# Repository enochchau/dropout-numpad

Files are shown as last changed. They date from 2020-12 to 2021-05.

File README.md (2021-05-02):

# Dropout 

(mechanical numpad w/ roatry encoder)

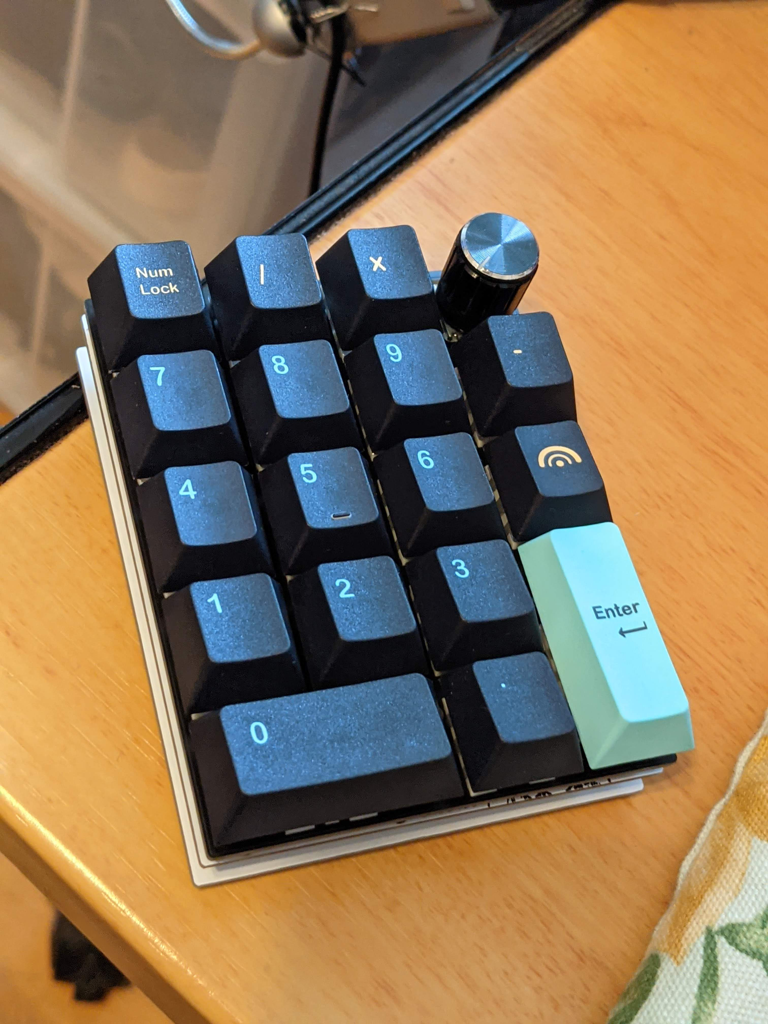
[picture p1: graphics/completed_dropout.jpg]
droput-completed


## Firmware
Dropout uses [QMK](https://github.com/qmk/qmk_firmware).
For now you'll have to use my fork of QMK under [the dropout-numpad branch](https://github.com/ec965/qmk_firmware/tree/dropout-numpad/keyboards/dropout).
If you know what you're doing, you can also copy the firmware files from this repository into your local QMK repository and compile it that way.

## Parts

### Case Parts
Amount | Part | Dimensions
--- | --- | ---
5 | M2 F-F standoffs | minimum: 13mm (mini usb) or 11mm (micro-usb)
10 | M2 screws | 5mm
4 | rubber bumpon feet

Sandwhich! case (parts in this order from top down)

1. Plate
2. PCB
3. Base

### PCB Components
Amount | Part | Package
--- | --- | ---
18 | diodes (1n4148 recommended) | SOD-123 (SMD) or DO-35 (THT)
1 | resistor (333 Ohms) | 0805
2 | capacitors (10nF) | 0805
1 | led | 1.8mm
1 | rotary encoder | EC-11
1 | push button | SPST PTS810
1 | pro-micro | usb-mini or usb-micro
16 | mx-switches | 
2 | 2U stabilizers | 

#### Notes
* Encoder can be swapped for a 1u switch.
  - If opting for the 1u switch, capacitors are not needed.
* If using encoder, capacitors can be omitted but resulting encoder signal will not be as smooth.
* Resistor can be omitted if num-lock led is not used.

## Build Guide

* The bottom of the PCB is the side without the stencil art of the person.
* The top of the PCB is the side with the stencil art person on it.
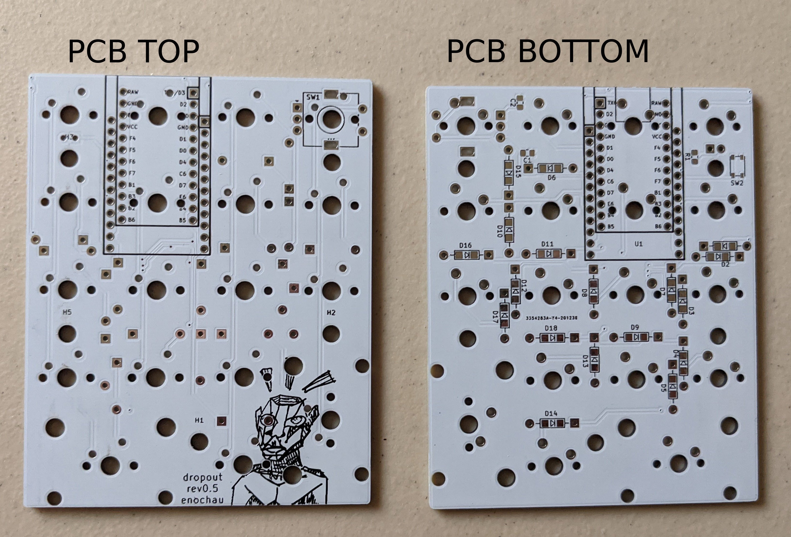
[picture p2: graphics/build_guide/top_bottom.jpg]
top and bottom of pcb


1. Start on the bottom of the PCB. Solder on all the diodes. Make sure that the diodes are in the correct direction. The diagram below should match up to the the symbol on the schematic and the physical diodes.
diode diagram
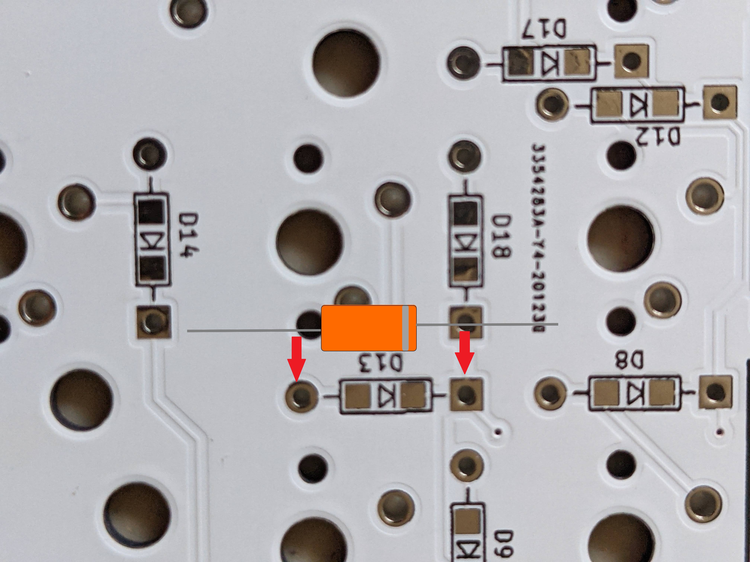
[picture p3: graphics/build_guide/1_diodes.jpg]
PCB diodes


2. Solder on capacitors C1 and C2. These are located near the rotary encoder.
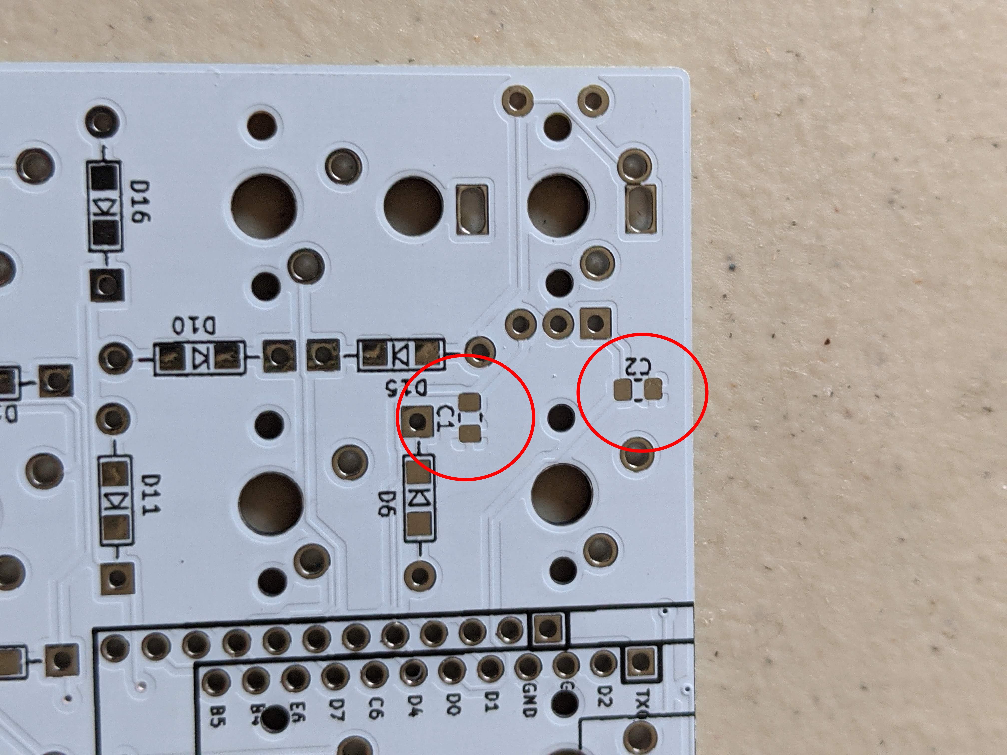
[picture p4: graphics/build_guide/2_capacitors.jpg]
capacitor location

capacitor soldered on

3. Solder on the resistor R1. It is near the num lock key. This resistor is to limit the current going to the num-lock led.

4. Solder on the SPST reset switch.
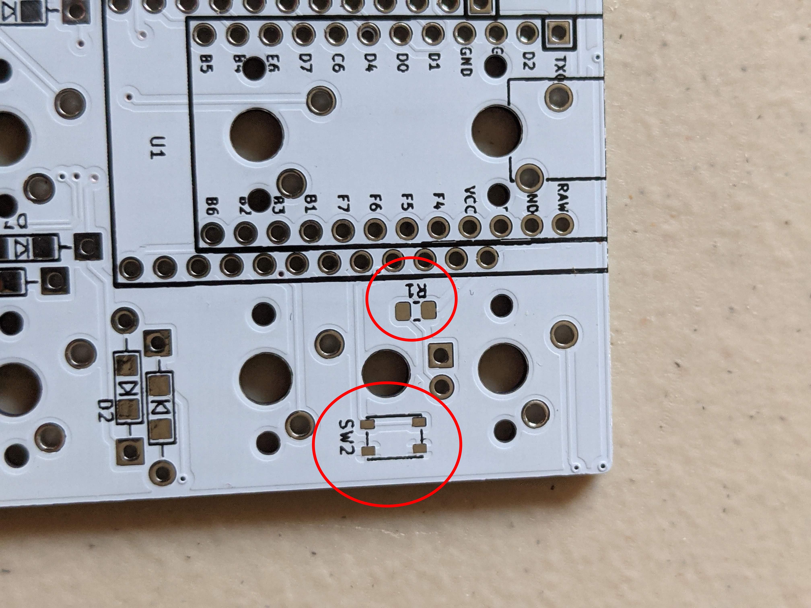
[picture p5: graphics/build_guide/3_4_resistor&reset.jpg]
resistor and reset switch

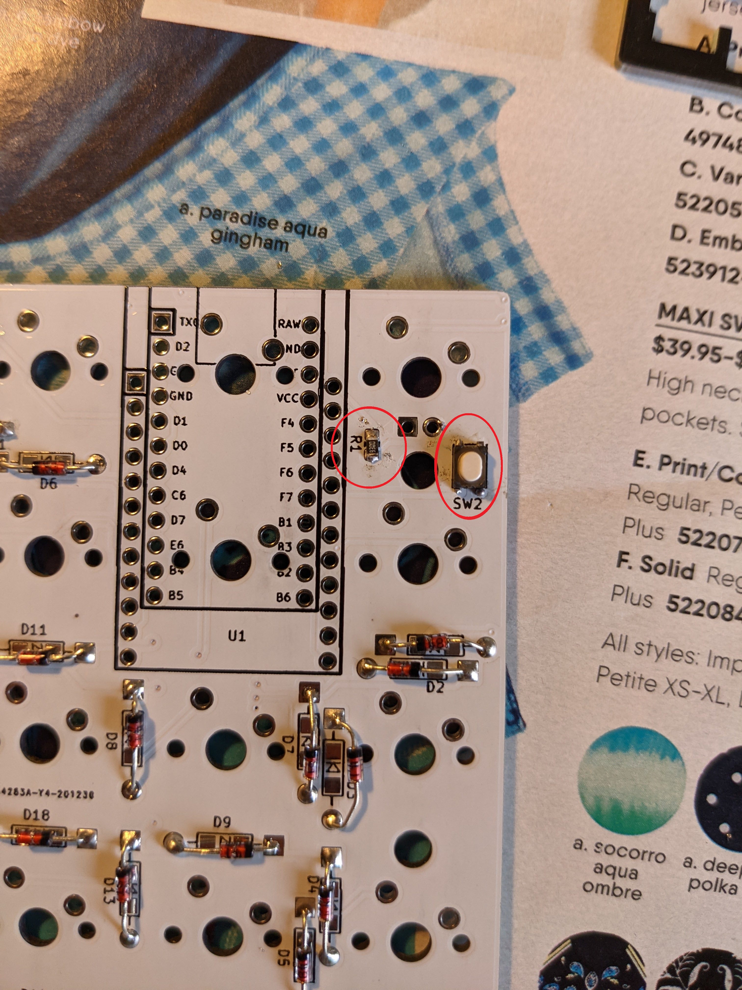
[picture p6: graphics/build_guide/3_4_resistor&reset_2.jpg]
resistor and reset switch soldered on


5. Solder on the Pro Micro header pins with the short side down. DO NOT solder on the Pro Micro.
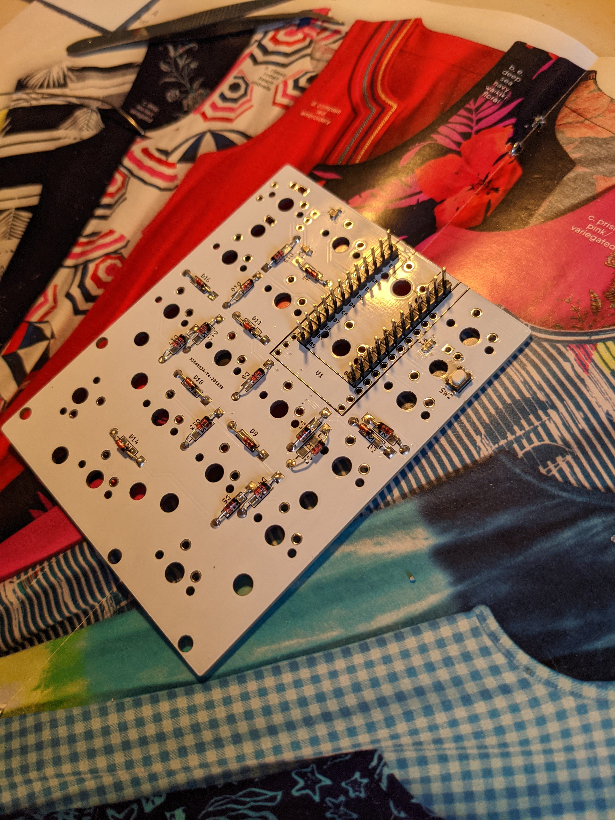
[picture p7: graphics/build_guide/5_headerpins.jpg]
head pin direction


6. Solder on the rotary encoder.
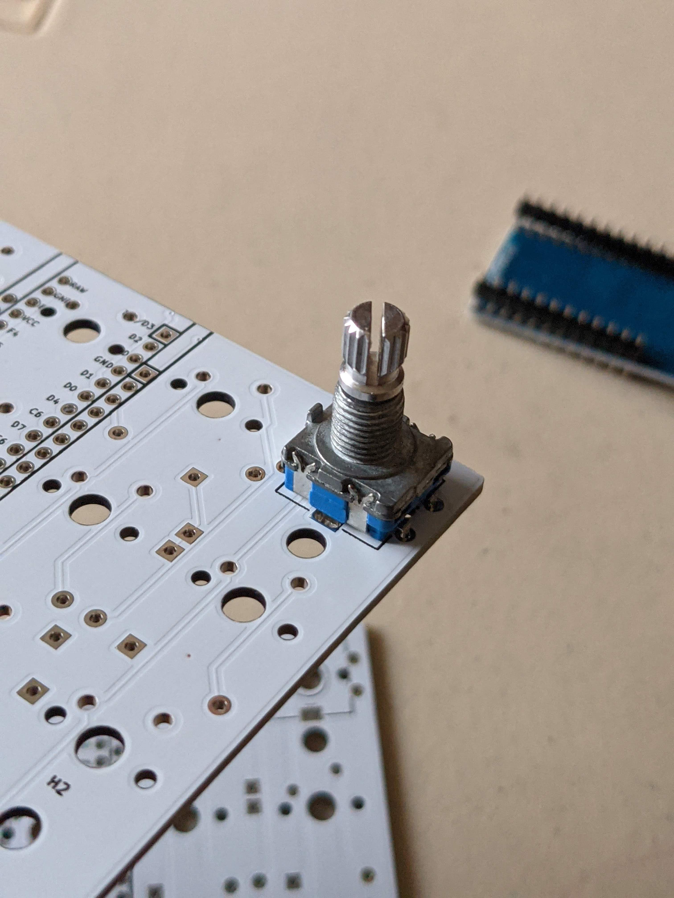
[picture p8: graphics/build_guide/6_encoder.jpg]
encoder


7. Flip the board over to the top side. You should now see the stencil art of the the person. Put two 2U stablizers on the board for the Zero and Enter keys.
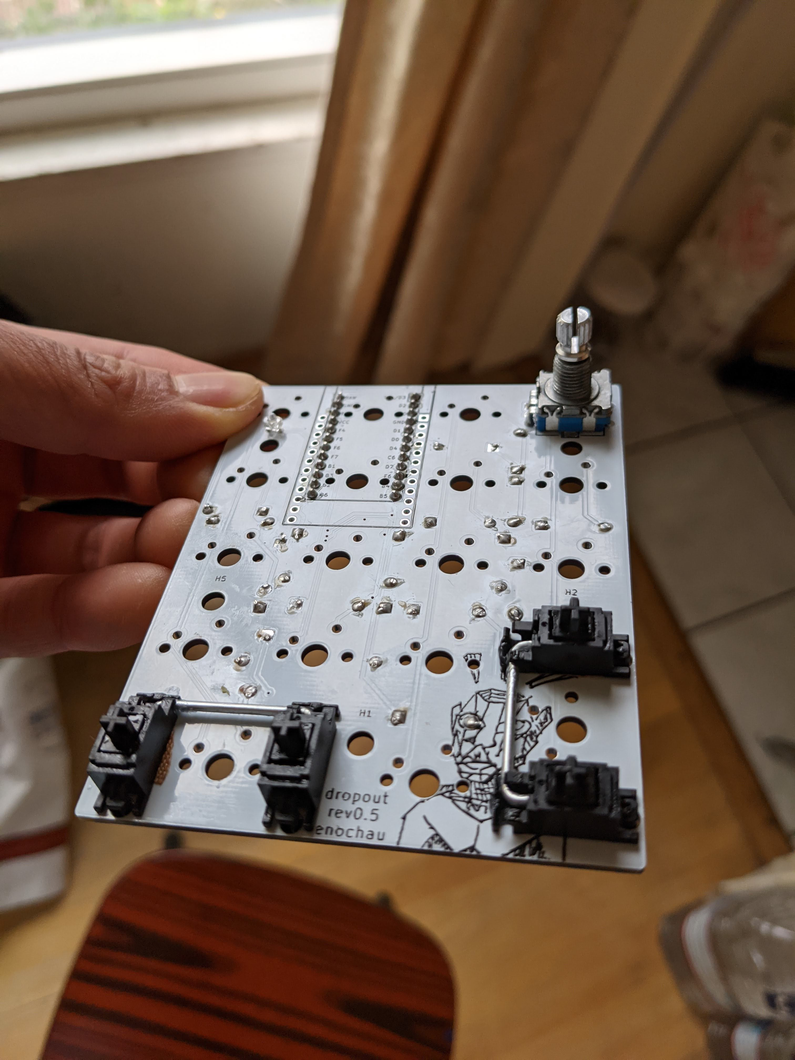
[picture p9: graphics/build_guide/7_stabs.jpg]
stabs on pcb

    1. If you are using Kailh Box switches, solder on the num-lock LED before putting the switch on the board.
    2. If you are using regular Cherry, Gateron, etc. you can wait to solder the num-lock LED after all the switches are soldered on.

The polarity of the led is shown below.
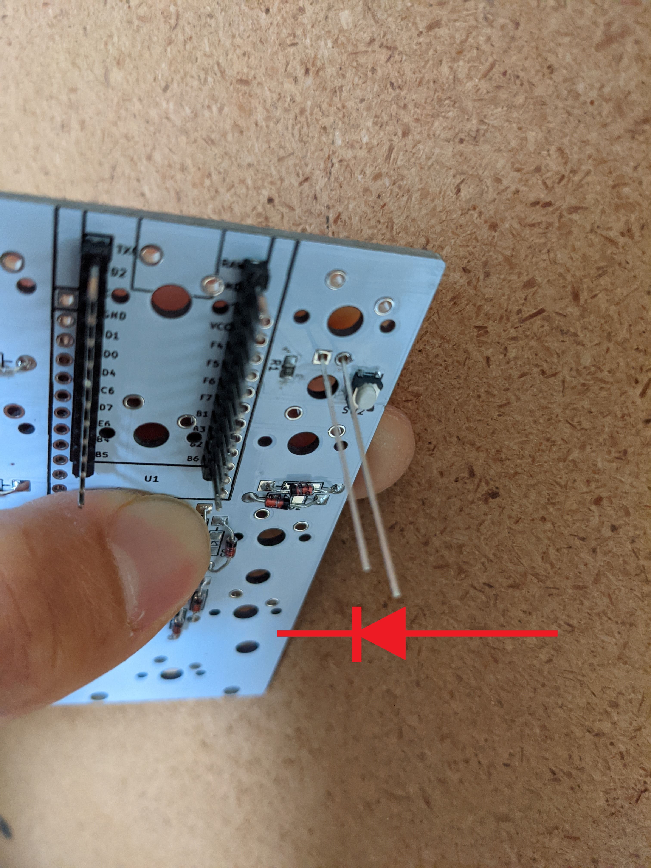
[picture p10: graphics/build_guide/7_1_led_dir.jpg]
led direction


8. Put the switches on the plate. Line up the plate with the pcb and push the two parts together. There may be some friction but as long as none of the switch pins get bent it is okay.
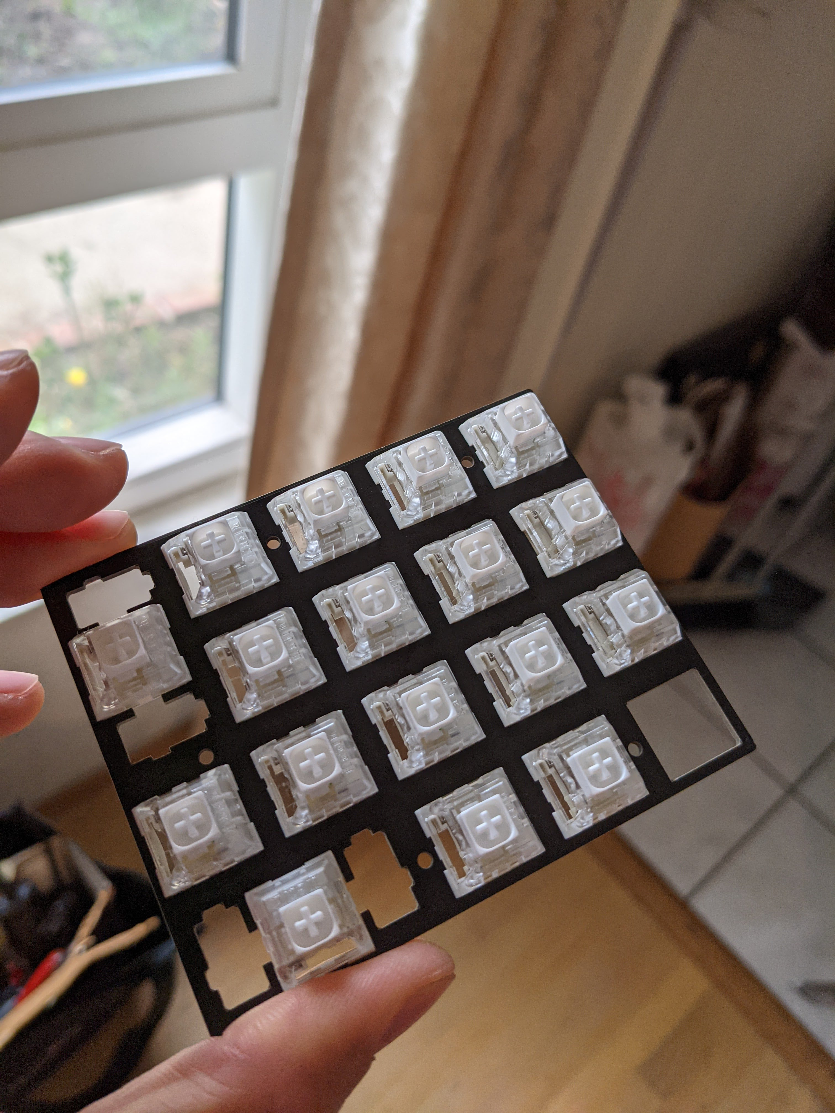
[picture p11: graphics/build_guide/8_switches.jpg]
switches in plate


9. Flip the PCB over to the bottom side. As you solder on the switches, apply some pressure to push the plate into the PCB to ensure that the switches are flush with the PCB.

10. Tape the Pro Micro onto the header pins. 
Clip the long header pins to be flush with the holes on the Pro Micro.
Then, solder the Pro Micro to the header pins.
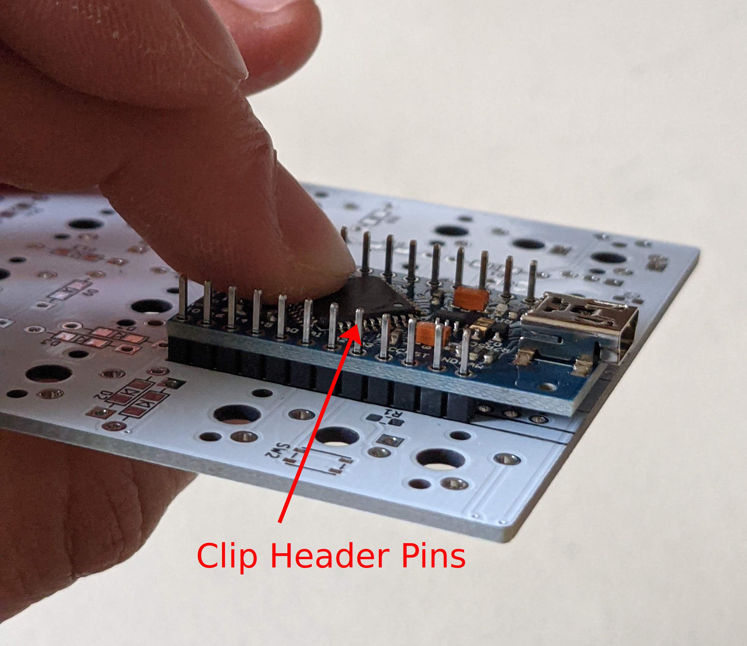
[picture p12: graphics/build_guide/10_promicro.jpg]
pro micro clip pins

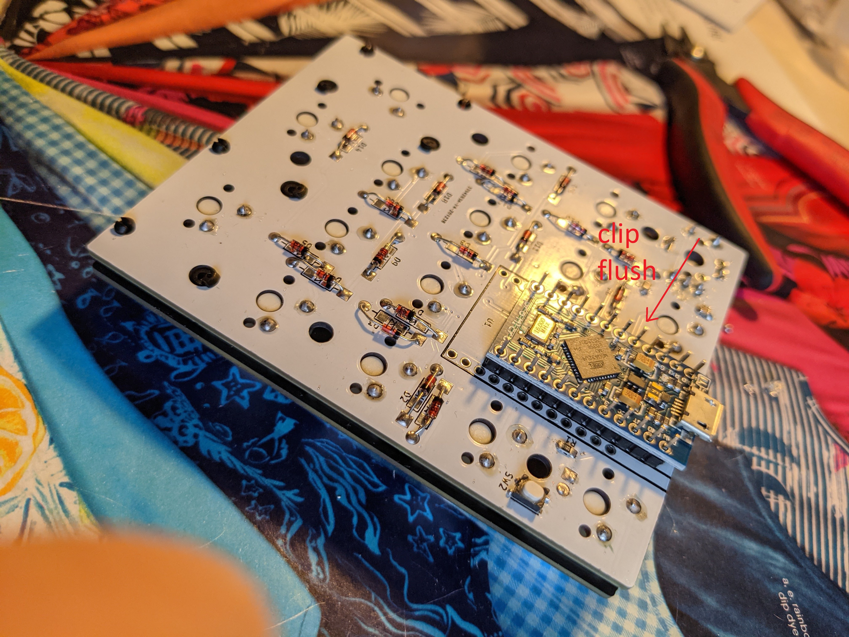
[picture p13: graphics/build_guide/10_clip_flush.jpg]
clip flush


11. Put the standoffs through the holes on the top of the plate and screw them in.

12. Get the bottom plate and screw the other end of the standoffs into the bottom plate. The standoffs should go through the holes in the PCB.
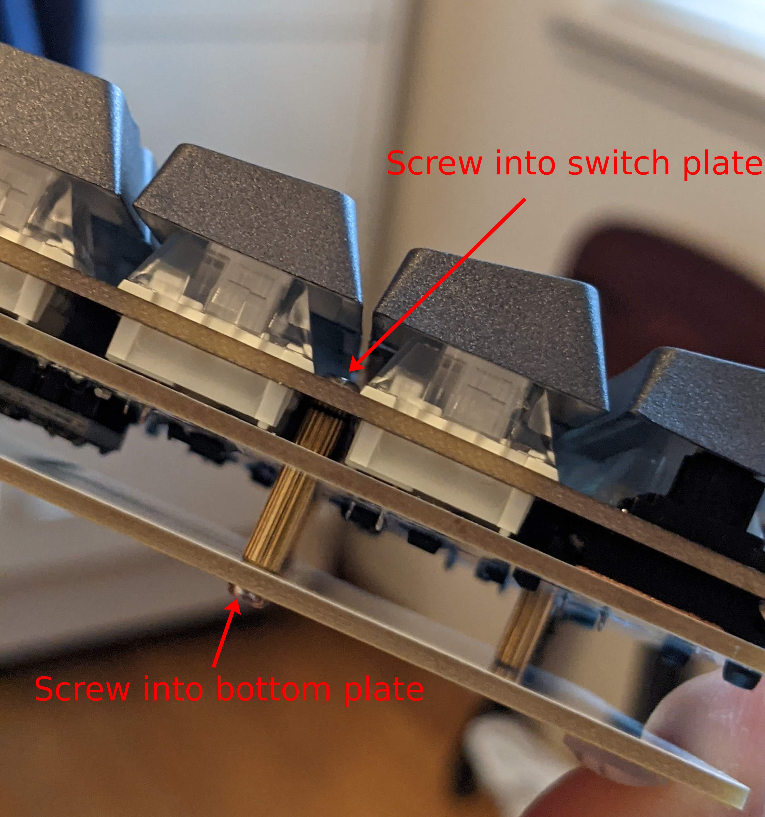
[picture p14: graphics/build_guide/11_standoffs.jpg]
stand-offs


13. Place rubber feet onto the bottom of the numpad.
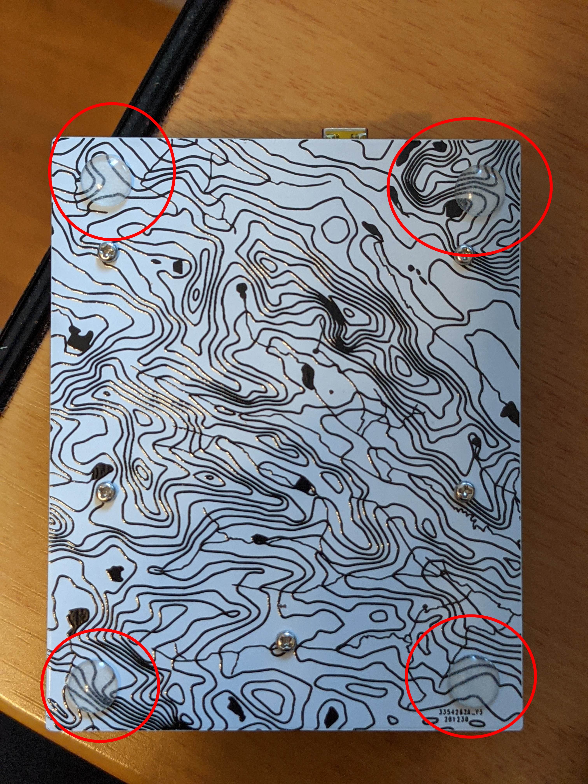
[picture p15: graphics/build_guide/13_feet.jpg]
rubber feet placement


## PCBs

* rev 0.5
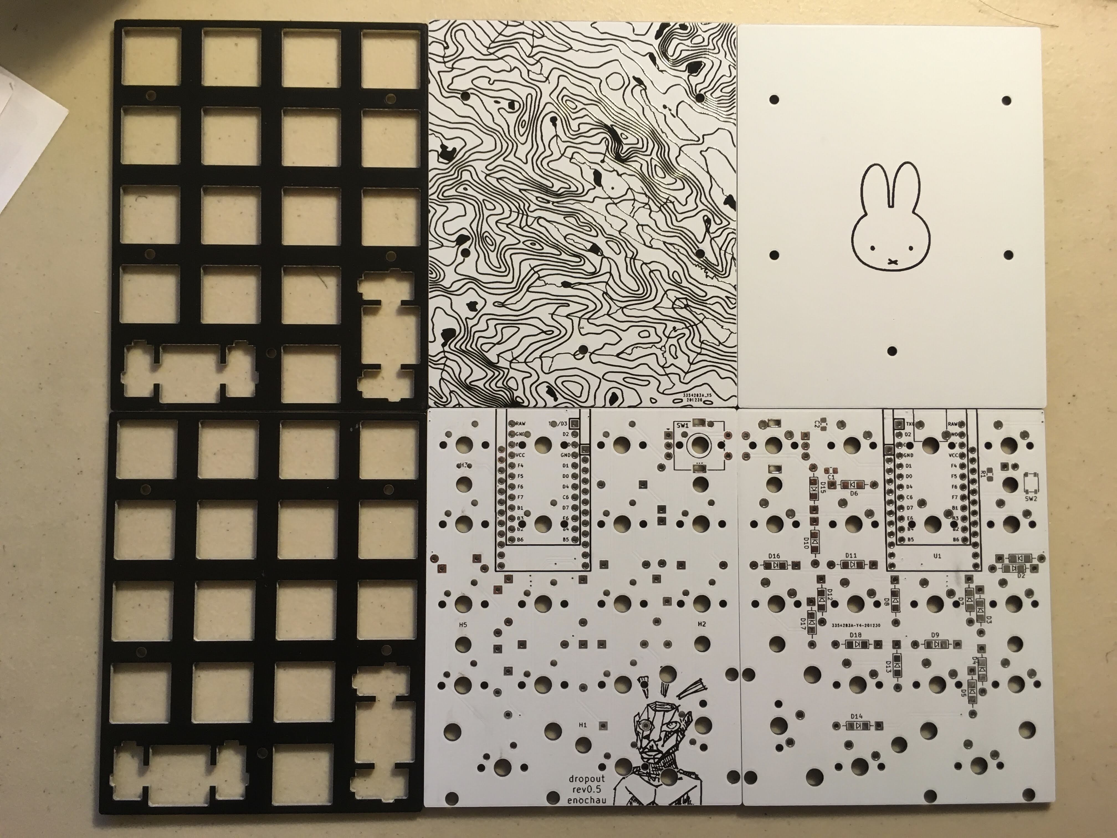
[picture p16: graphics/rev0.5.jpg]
rev0.5

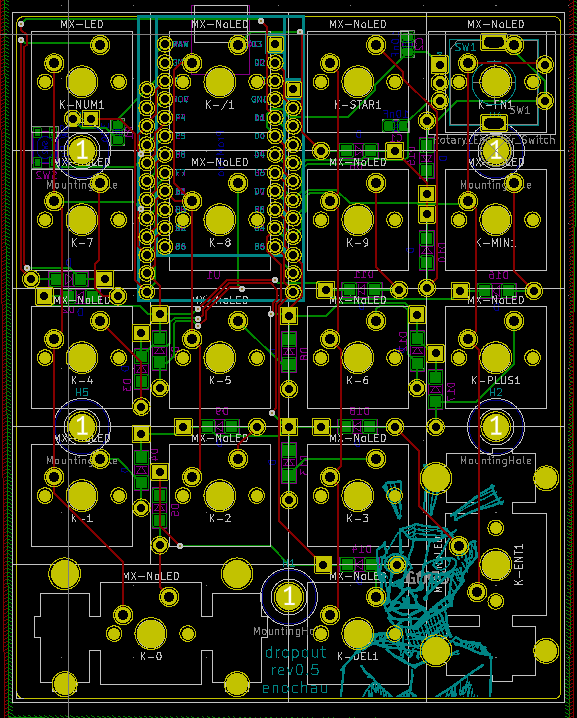
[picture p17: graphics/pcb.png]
pcb PCB

* rev 0.1
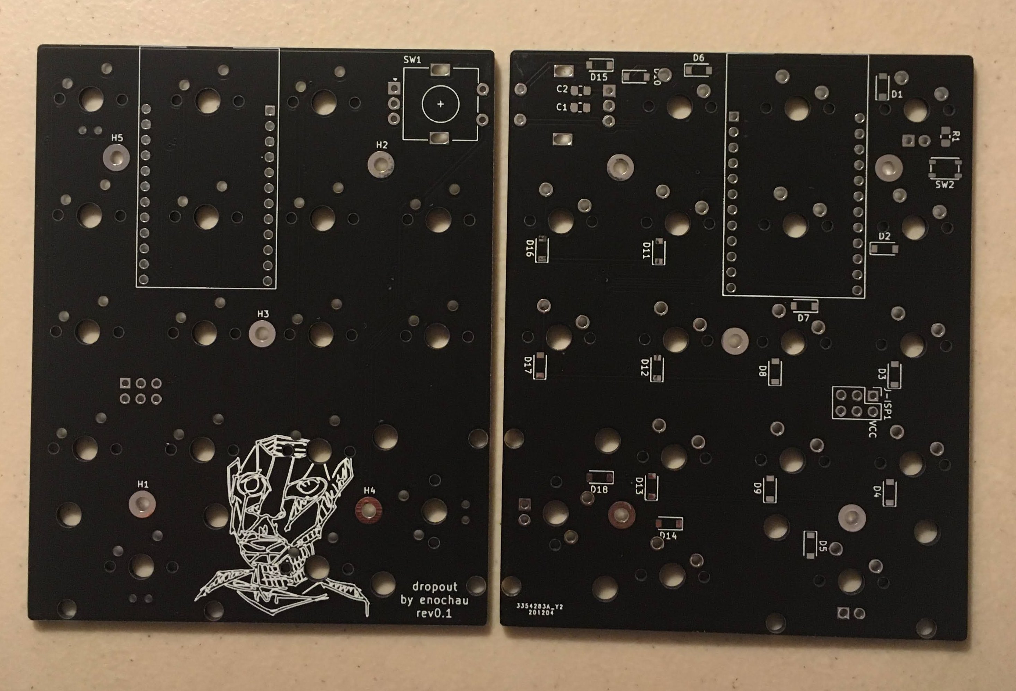
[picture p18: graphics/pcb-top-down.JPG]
rev0.1


## License

Hardware designs are under the MIT license. QMK is under the GPL v2 license therefore, the firmware is also under the GPLv2 license.

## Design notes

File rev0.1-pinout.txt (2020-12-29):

Rows
0: D1
1: B2
2: E6
3: B4
4: B5

Cols
0: B3
1: B1
2: D7
3: C6

Backlight: B6

Encoder:
A: D0
B: D4

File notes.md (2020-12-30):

# Notes

## Updates
PCBs are labelled with revision number in the lower right corner.

* 12/29 - Rev0.5 Fixed plate outline to match stab orientation. Got rid of panelization.
* 12/29 - Rev0.5 Flipped ProMicro and redrew traces. There isn't enough clearance for the pro-micro to sit flush against the pcb. Rev0.5 now uses the same pinout as Rev0.1.
* 12/28 - Rev0.5 Replaced SOD123 diode footprints with THT/SOD123 dual footprint. Removed ISP and I2C header pins. Cleaned up schematic and footprints.
* 12/11 - Rev0.4 Added compatibility for ProMicro with mini-usb or micro-usb on same pcb, flipped orientation of ProMicro, and cleaned up traces.
Added option for switch or rotary encoder. Added I2C header.
* 12/6 - Rev0.3 Added mouse-bites to print all parts on a single PCB.
* 12/? - Rev0.2 uses ProMicro (mini-usb). Mounting holes have been moved to prevent interference with stablizier wire. Board outline was also slightly adjusted. I also created a plate pcb. Because some dimensions changed between rev0.1 and rev0.2, the plate will not fit on older revisions.
* 12/? - Rev0.1 uses ProMicro with mini-usb as can be found by various retailers elsewhere on the internet. 
Dimensions for the ProMicro mini-usb are 39.5mm x 23mm. I do not garantee that your ProMicro will fit the board.
* 12/? - Rev0 uses ProMicro with micro-usb as designed by [Sparkfun](https://www.sparkfun.com/products/12640).

### M2 F-F standoff calculations:
#### For mini-usb
**5mm** _from top of plate to top of pcb_ **- 1.6mm** _thickness of plate_ **+ 1.6mm** _thickness of pcb_ **+ ~6mm** _thickness pro-micro usb mini_ **+ 2mm** _thickness of header pins_ **= 13mm**
#### For micro-usb
**5mm** _from top of plate to top of pcb_ **- 1.6mm** _thickness of plate_ **+ 1.6mm** _thickness of pcb_ **+ ~4mm** _thickness pro-micro usb mini_ **+ 2mm** _thickness of header pins_ **= 11mm**

## Q&A
Where does the name come from?

I designed this shortly after deciding to dropout.

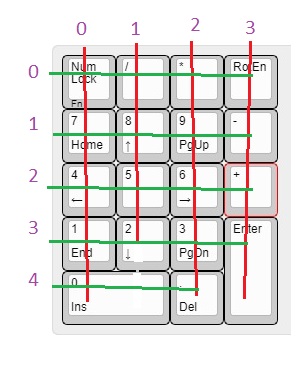
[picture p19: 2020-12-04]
graphics/design_files/keyboard-layout.jpg

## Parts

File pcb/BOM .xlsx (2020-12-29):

Reference | Quantity | Value | Footprint | Datasheet | Notes
D1 D2 D3 D4 D5 D6 D7 D8 D9 D10 D11 D12 D13 D14 D15 D16 D17 D18 | 18 | D | Diode_SMD:D_SOD-123 | ~
H1 H2 H3 H4 H5 | 5 | MountingHole | MountingHole:MountingHole_2.2mm_M2_Pad | ~ | screws and poles (8mm)
K-/1 K-STAR1 K-MIN1 K-PLUS1 K-1 K-DEL1 K-2 K-3 K-4 K-5 K-6 K-7 K-8 K-9 | 14 | MX-NoLED | MX_Only:MXOnly-1U-NoLED | Kailh Box Whites
K-0 K-ENT1 | 2 | MX-NoLED | MX_Only:MXOnly-2U-NoLED |  | 2u stabs
K-NUM1 | 1 | MX-LED | MX_Only:MXOnly-1U
R1 | 1 | 333 | Resistor_SMD:R_0805_2012Metric_Pad1.15x1.40mm_HandSolder | ~
SW1 | 1 | Rotary_Encoder_Switch | Rotary_Encoder:RotaryEncoder_Alps_EC11E-Switch_Vertical_H20mm | ~ | knob and encoder
SW2 | 1 | SW_Push | Button_Switch_SMD:SW_SPST_PTS810 | ~
U1 | 1 | ProMicro | promicro:ProMicro |  | mini usb, 39.5mmx23mm
PCB
C1 C2 | 2 | 10nF | 805

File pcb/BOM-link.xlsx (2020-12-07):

Reference | Quantity | Value | Footprint | Datasheet | amount | price | Total | Notes | Purchase link
D1 D2 D3 D4 D5 D6 D7 D8 D9 D10 D11 D12 D13 D14 D15 D16 D17 D18 | 18 | D | Diode_SMD:D_SOD-123 | ~ | 40 | 1.44 | 5.76 |  | https://www.digikey.com/en/products/detail/diodes-incorporated/1N4148W-7-F/814371
H1 H2 H3 H4 H5 | 5 | MountingHole | MountingHole:MountingHole_2.2mm_M2_Pad | ~ |  |  | 3.1 | screws and poles (8mm)
K-/1 K-STAR1 K-MIN1 K-PLUS1 K-1 K-DEL1 K-2 K-3 K-4 K-5 K-6 K-7 K-8 K-9 | 14 | MX-NoLED | MX_Only:MXOnly-1U-NoLED | Kailh Box Whites | 70 |  | 27.3 | box whites | https://www.aliexpress.com/item/32879369291.html
K-0 K-ENT1 | 2 | MX-NoLED | MX_Only:MXOnly-2U-NoLED |  | 4 |  | 5.9 | 2u stabs | https://www.aliexpress.com/item/32831318362.html?scm_id=1007.13338.183347.0&scm-url=1007.13338.183347.0
K-NUM1 | 1 | MX-LED | MX_Only:MXOnly-1U
R1 | 1 | 330 | Resistor_SMD:R_0805_2012Metric_Pad1.15x1.40mm_HandSolder | ~ | 5 |  | 0.5 |  | https://www.digikey.com/en/products/detail/te-connectivity-passive-product/CRG0805F330R/2380889
SW1 | 1 | Rotary_Encoder_Switch | Rotary_Encoder:RotaryEncoder_Alps_EC11E-Switch_Vertical_H20mm | ~ |  |  | 3.75 | knob and encoder | https://www.aliexpress.com/item/32873198060.html?scm_id=1007.13339.169870.0&scm-url=1007.13339.169870.0 | https://www.aliexpress.com/item/32889562286.html?spm=2114.12010615.8148356.17.2f6b50311E8rPt
SW2 | 1 | SW_Push | Button_Switch_SMD:SW_SPST_PTS810 | ~ | 5 |  | 1.6 |  | https://www.digikey.com/en/products/detail/c-k/PTS810-SJM-250-SMTR-LFS/4176610
U1 | 1 | ProMicro | promicro:ProMicro |  |  |  |  | mini usb, 39.5mmx23mm
PCB |  |  |  |  |  |  | 9.12 |  | jlcjpcb.com
C1 C2 | 2 | 10nF | 805 |  | 10 | 0.14 | 0.7 |  | https://www.digikey.com/en/products/detail/kemet/C0805X103K1RAC3316/10315780
 |  |  |  |  |  | Total | 57.03

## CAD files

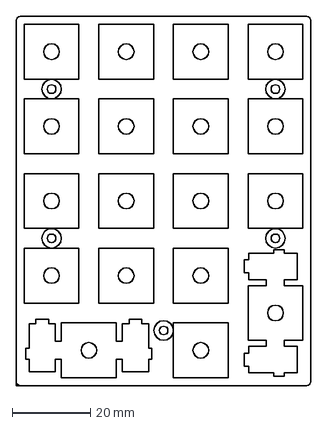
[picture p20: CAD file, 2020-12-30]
graphics/design_files/outline.dxf
75.1 x 94.2 mm

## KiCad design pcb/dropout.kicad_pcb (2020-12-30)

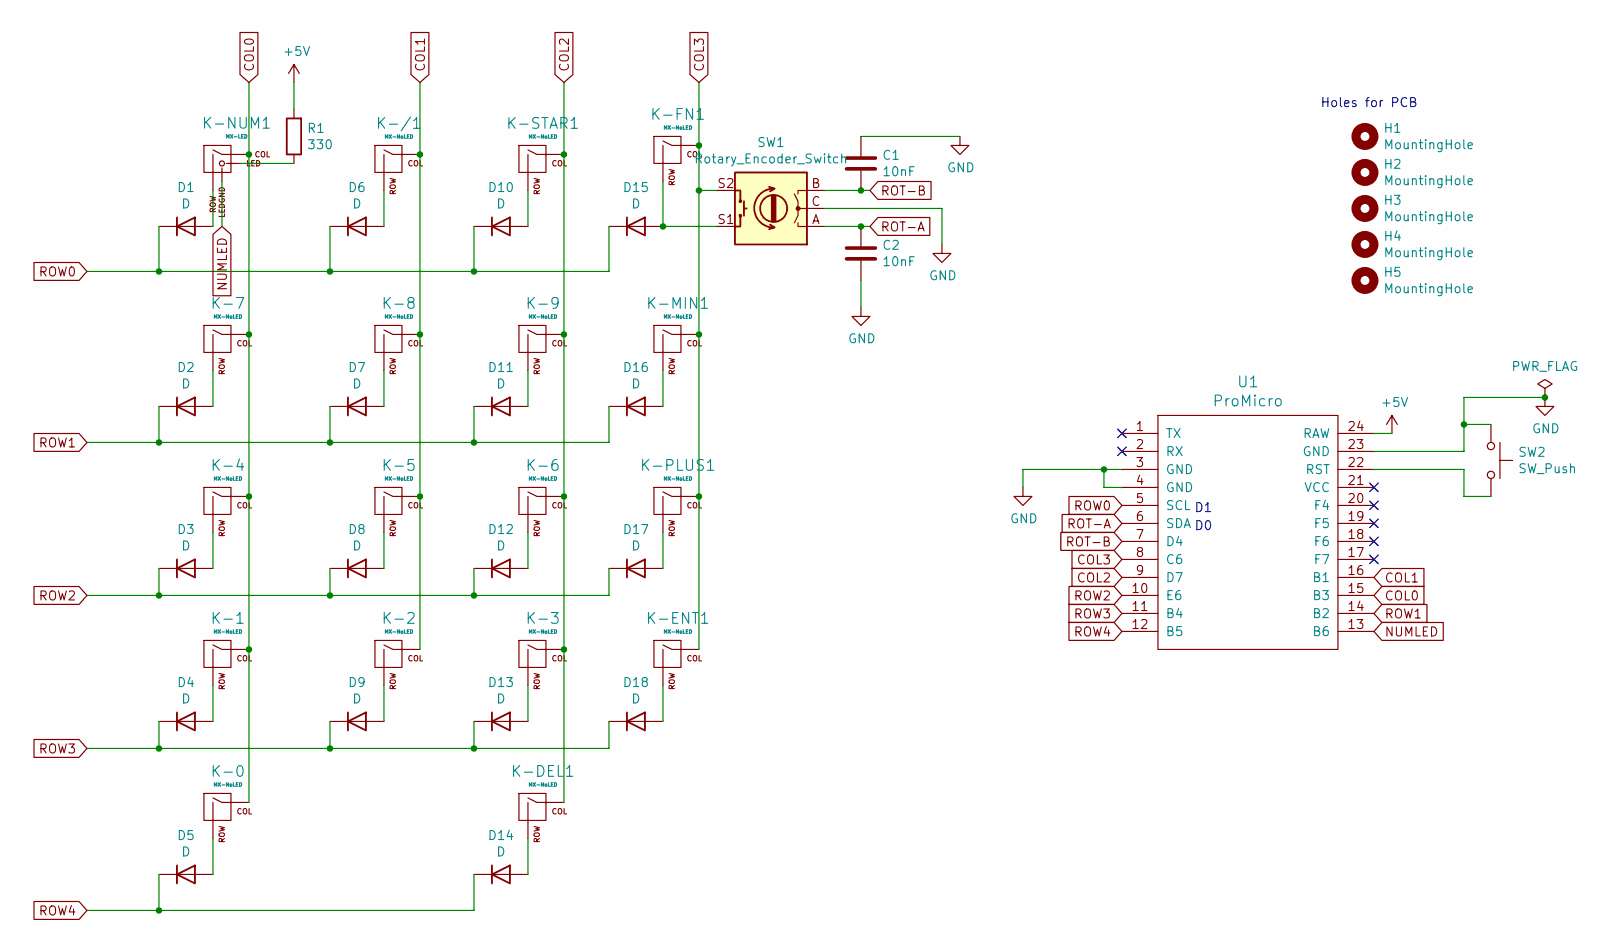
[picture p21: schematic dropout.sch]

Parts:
C1, C2: 10nF; C_0805_2012Metric_Pad1.15x1.40mm_HandSolder
D1, D2, D3, D4, D5, D6, D7, D8, D9, D10, D11, D12, D13, D14, D15, D16, D17, D18: D; Diode_TH_SOD123
H1, H2, H3, H4, H5: MountingHole; MountingHole_3.7mm
K-0: MX-NoLED; MXOnly-2U-ReversedStabilizers-NoLED
K-1, K-2, K-3, K-4, K-5, K-6, K-7, K-8, K-9: MX-NoLED; MXOnly-1U-NoLED
K-/1: MX-NoLED; MXOnly-1U-NoLED
K-DEL1: MX-NoLED; MXOnly-1U-NoLED
K-ENT1: MX-NoLED; MXOnly-2U-ReversedStabilizers-NoLED
K-FN1: MX-NoLED; MXOnly-1U-NoLED
K-MIN1: MX-NoLED; MXOnly-1U-NoLED
K-NUM1: MX-LED; MXOnly-1U
K-PLUS1: MX-NoLED; MXOnly-1U-NoLED
K-STAR1: MX-NoLED; MXOnly-1U-NoLED
R1: 330; R_0805_2012Metric_Pad1.15x1.40mm_HandSolder
SW1: Rotary_Encoder_Switch; RotaryEncoder_Alps_EC11E-Switch_Vertical_H20mm
SW2: SW_Push; SW_SPST_PTS810
U1: ProMicro; ProMico_mini&micro

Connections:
+5V: R1.2, U1.24 (RAW)
COL0: K-0.1 (COL), K-1.1 (COL), K-4.1 (COL), K-7.1 (COL), K-NUM1.1 (COL), U1.15 (B3)
COL1: K-2.1 (COL), K-5.1 (COL), K-8.1 (COL), K-/1.1 (COL), U1.16 (B1)
COL2: K-3.1 (COL), K-6.1 (COL), K-9.1 (COL), K-DEL1.1 (COL), K-STAR1.1 (COL), U1.9 (D7)
COL3: K-ENT1.1 (COL), K-FN1.1 (COL), K-MIN1.1 (COL), K-PLUS1.1 (COL), SW1.S2, U1.8 (C6)
GND: C1.1, C2.2, SW1.C, SW2.1, U1.3 (GND), U1.4 (GND), U1.23 (GND)
NUMLED: K-NUM1.4 (LEDGND), U1.13 (B6)
unnamed: D1.2 (A), K-NUM1.2 (ROW)
unnamed: D2.2 (A), K-7.2 (ROW)
unnamed: D3.2 (A), K-4.2 (ROW)
unnamed: D4.2 (A), K-1.2 (ROW)
unnamed: D5.2 (A), K-0.2 (ROW)
unnamed: D6.2 (A), K-/1.2 (ROW)
unnamed: D7.2 (A), K-8.2 (ROW)
unnamed: D8.2 (A), K-5.2 (ROW)
unnamed: D9.2 (A), K-2.2 (ROW)
unnamed: D10.2 (A), K-STAR1.2 (ROW)
unnamed: D11.2 (A), K-9.2 (ROW)
unnamed: D12.2 (A), K-6.2 (ROW)
unnamed: D13.2 (A), K-3.2 (ROW)
unnamed: D14.2 (A), K-DEL1.2 (ROW)
unnamed: D15.2 (A), K-FN1.2 (ROW), SW1.S1
unnamed: D16.2 (A), K-MIN1.2 (ROW)
unnamed: D17.2 (A), K-PLUS1.2 (ROW)
unnamed: D18.2 (A), K-ENT1.2 (ROW)
unnamed: K-NUM1.3 (LED), R1.1
unnamed: SW2.2, U1.22 (RST)
ROT-A: C2.1, SW1.A, U1.6 (SDA)
ROT-B: C1.2, SW1.B, U1.7 (D4)
ROW0: D1.1 (K), D6.1 (K), D10.1 (K), D15.1 (K), U1.5 (SCL)
ROW1: D2.1 (K), D7.1 (K), D11.1 (K), D16.1 (K), U1.14 (B2)
ROW2: D3.1 (K), D8.1 (K), D12.1 (K), D17.1 (K), U1.10 (E6)
ROW3: D4.1 (K), D9.1 (K), D13.1 (K), D18.1 (K), U1.11 (B4)
ROW4: D5.1 (K), D14.1 (K), U1.12 (B5)

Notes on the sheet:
Holes for PCB

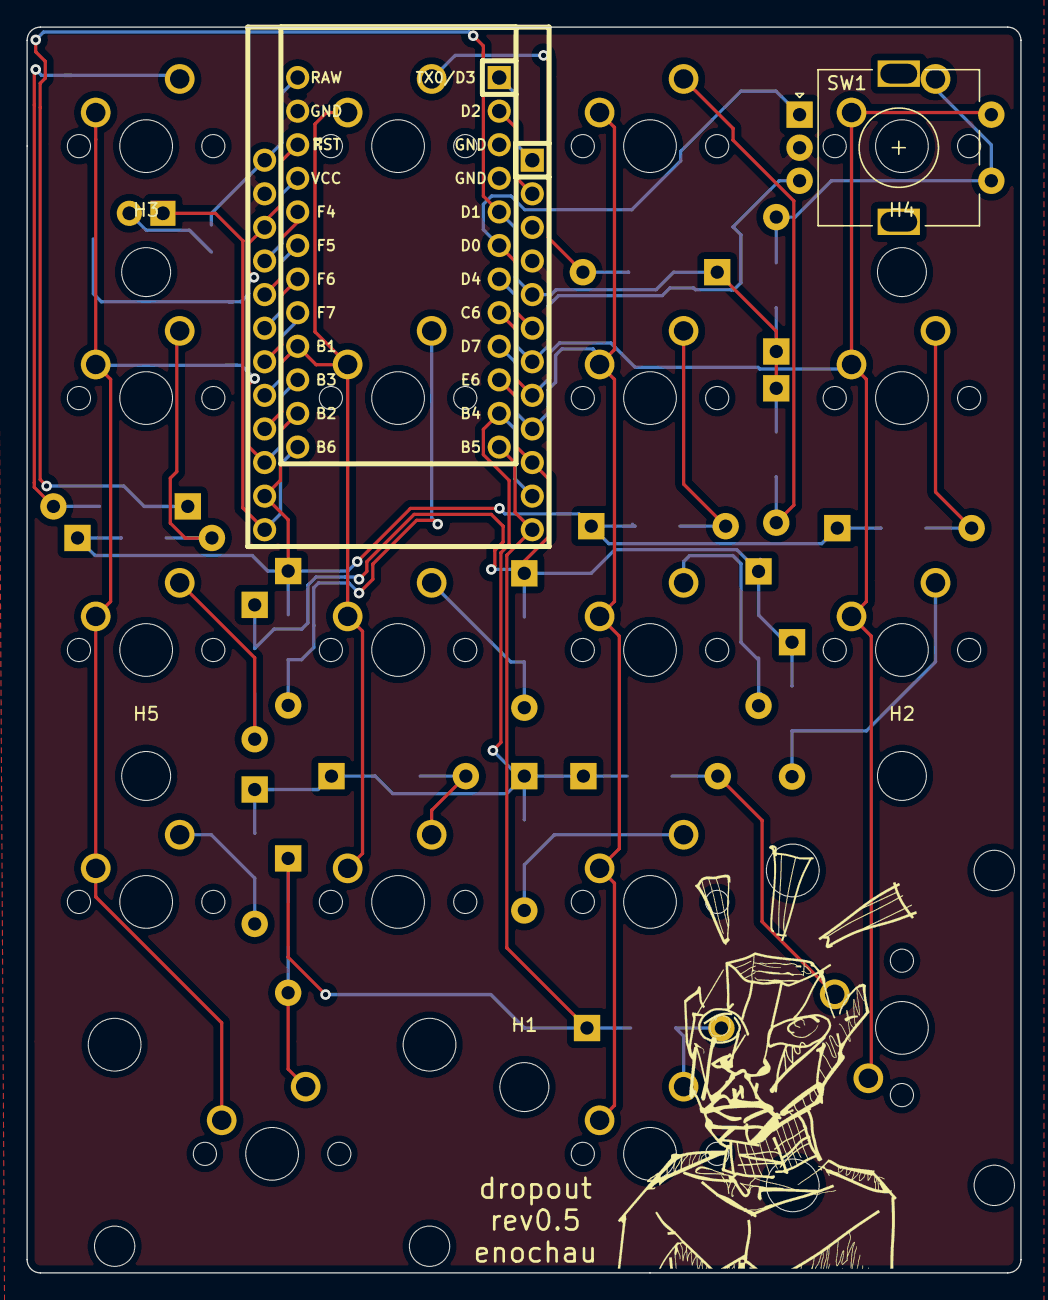
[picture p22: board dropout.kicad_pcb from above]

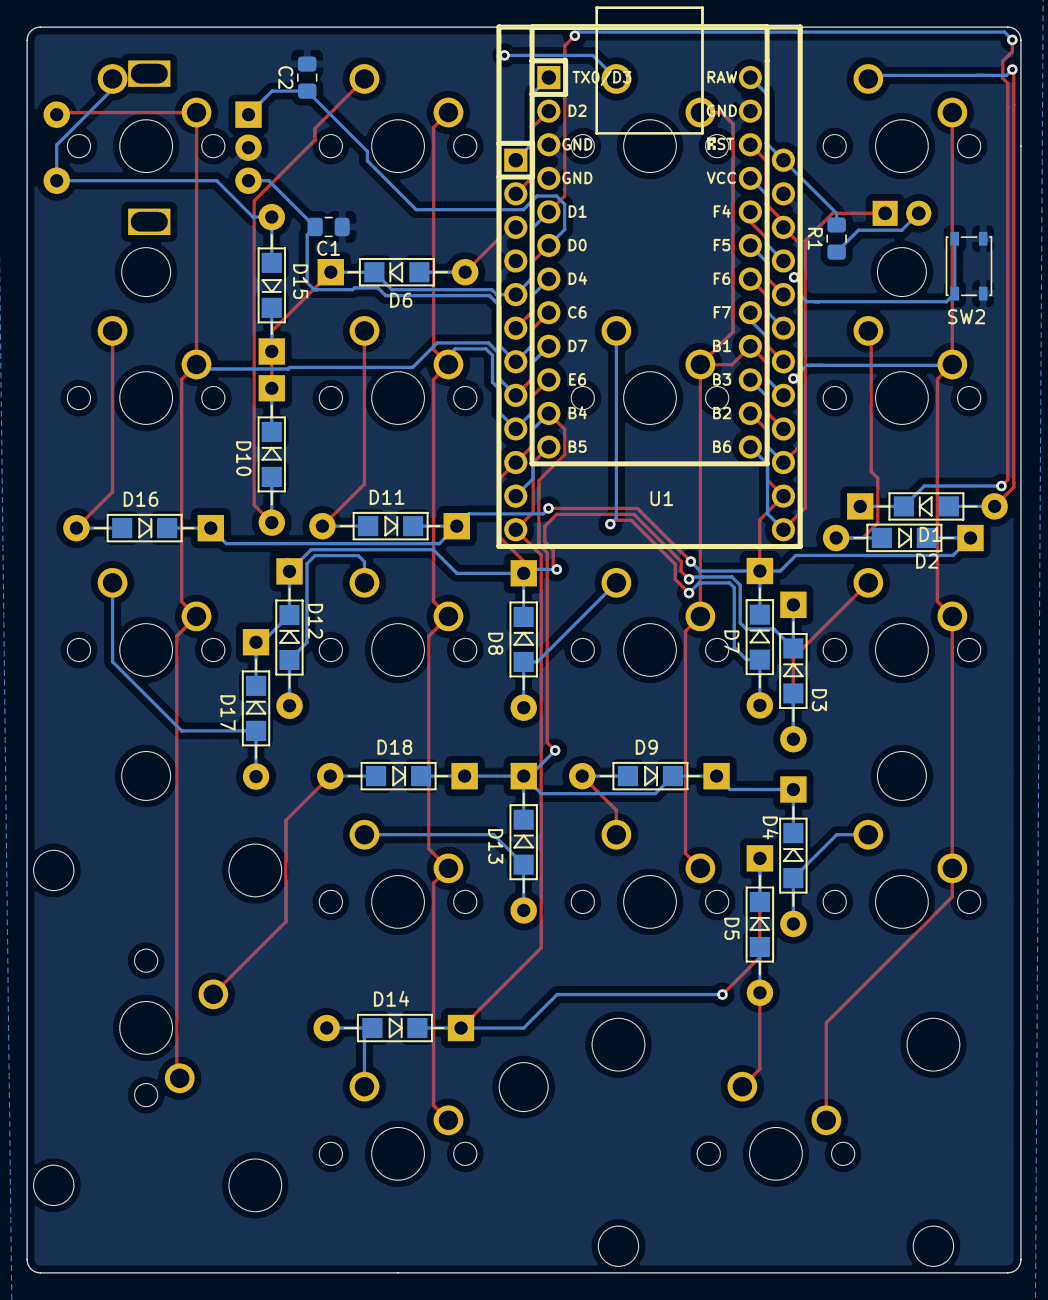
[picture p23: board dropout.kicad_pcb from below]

Board: 2 copper layers, 75.1 x 94.2 mm, 47 parts (23 on the bottom side), 34 nets.

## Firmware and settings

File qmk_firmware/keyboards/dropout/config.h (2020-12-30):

#ifndef CONFIG_H
#define CONFIG_H

#include "config_common.h"

/* USB Device descriptor parameter */
#define VENDOR_ID       0x9650
#define PRODUCT_ID      0x2800
#define DEVICE_VER 		0x0001
#define MANUFACTURER    github.com/ec965
#define PRODUCT         dropout 
#define DESCRIPTION     numpad

/* key matrix size */
#define MATRIX_ROWS 5
#define MATRIX_COLS 4

/* key matrix pins */
#define MATRIX_ROW_PINS { D1, B2, E6, B4, B5 }
#define MATRIX_COL_PINS { B3, B1, D7, C6 }
#define UNUSED_PINS

/* COL2ROW or ROW2COL */
#define DIODE_DIRECTION COL2ROW

/* Set 0 if debouncing isn't needed */
#define DEBOUNCING_DELAY 5

/* Mechanical locking support. Use KC_LCAP, KC_LNUM or KC_LSCR instead in keymap */
#define LOCKING_SUPPORT_ENABLE

/* Locking resynchronize hack */
#define LOCKING_RESYNC_ENABLE

/* key combination for command */
#define IS_COMMAND() ( \
    keyboard_report->mods == (MOD_BIT(KC_LSHIFT) | MOD_BIT(KC_RSHIFT)) \
)

/* prevent stuck modifiers */
#define PREVENT_STUCK_MODIFIERS


// This keyboard uses the backlight implementation for the numlock.
// Therefore, the user can control the brightness of the numlock led using backlight controls.
// there is only 1 switch led which is on the numlock key (on the default keymap).
// define BACKLIGHT_NUMLOCK to use the backlight implementation to control the numlock led
// if BACKLIGHT_NUMLOCK is not defined, the regular numlock implementation will be used.
#define BACKLIGHT_NUMLOCK
#ifdef BACKLIGHT_NUMLOCK
    #define BACKLIGHT_PIN B6
#else
    #define LED_NUM_LOCK_PIN B6
#endif

#define BACKLIGHT_LEVELS 6
/* #define BACKLIGHT_BREATHING */
#define BACKLIGHT_ON_STATE 0 //baklight is on when pin is low

#define ENCODERS_PAD_A { D0 }
#define ENCODERS_PAD_B { D4 }

#endif

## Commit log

2020-12-04 micro usb promicro
    [BOM .xlsx, BOM-link.xlsx, BOM-links.xlsx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]
2020-12-04 remove bom w/ purchase links
    [BOM-links.xlsx]
2020-12-04 remove purchase link BOM
    [BOM-link.xlsx]
2020-12-04 add caps for encoder
    [dropout-microusb-B_Cu.gbr, dropout-microusb-B_Mask.gbr, dropout-microusb-B_SilkS.gbr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]
2020-12-04 move screws away from stabs
    [dropout-microusb-B_Cu.gbr, dropout-microusb-B_Mask.gbr, dropout-microusb-B_SilkS.gbr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]
2020-12-07 3 piece panelization
    [BOM .xlsx, BOM-link.xlsx, dropout-microusb.kicad_pcb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]
2020-12-08 adding copper plated mounting holes
    [dropout-miniusb.kicad_pcb, dropout-miniusb.sch, outline.dxf]
2020-12-12 rev 0.4
    [dropout-miniusb-B_Cu.gbr, dropout-miniusb-B_Mask.gbr, dropout-miniusb-B_SilkS.gbr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]
2020-12-12 generate gerbers for rev0.4
    [BOM .xlsx, dropout-microusb.kicad_pcb, dropout-microusb.sch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]
2020-12-12 labels for orientation of pro-micro
    [dropout-miniusb.kicad_pcb]
2020-12-12 qmk backlight numlock
    [dropout-miniusb.kicad_pcb, dropout-miniusb.sch]
2020-12-12 rename cleanup
    [BOM .xlsx, BOM-link.xlsx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]
2020-12-12 update gerbers
    [dropout-B_Cu.gbr, dropout-B_Mask.gbr, dropout-B_SilkS.gbr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]
2020-12-13 alt-layout, replace encoder w/ switch
    [dropout.kicad_pcb, dropout.sch]
2020-12-13 5v -> led -> pin (numlock led)
    [dropout.kicad_pcb, dropout.sch]
2020-12-13 i2c trrs connectors
    [dropout.kicad_pcb, dropout.sch]
2020-12-13 replace i2c trrs with header pins
    [dropout.kicad_pcb, dropout.sch]
2020-12-28 updating to rev0.5
    updating to rev0.5
    [dropout.kicad_pcb, dropout.sch]
2020-12-29 updating gerbers
    [dropout-B_Cu.gbr, dropout-B_Mask.gbr, dropout-B_SilkS.gbr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]
2020-12-29 moving diodes to stop interference with stabilizer
    [dropout-B_Cu.gbr, dropout-B_Mask.gbr, dropout-B_SilkS.gbr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]
2020-12-29 flipping orientation of promicro for better clearance, now uses same pinout as rev0.1
    [dropout-B_Cu.gbr, dropout-B_Mask.gbr, dropout-B_SilkS.gbr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]
2020-12-30 adding graphics to pcb, some cleanup
    [dropout.kicad_pcb, dropout.sch, outline.dxf]
2020-12-30 updating firmware
    [graphic-bottom.dxf, graphic-pcb.dxf, outline.dxf]
2020-12-30 updating spacer measurements
2020-12-30 flipped orientation of stab outline to match pcb
    [outline.dxf]
2020-12-30 breaking up panelization for production
    [base-B_Cu.gbr, base-B_Mask.gbr, base-B_SilkS.gbr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]
2021-01-12 updating pics for rev0.5 pcb
